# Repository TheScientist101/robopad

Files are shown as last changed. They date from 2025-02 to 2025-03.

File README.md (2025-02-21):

# Robopad

The Robopad was designed because no controllers are mapped correctly for robot simulation. The main features I needed were the two joysticks but I decided to add some sliders to allow me to control the brightness of my screen and some keyswitches to allow me to have more inputs when I need them. Along with the keyswitches, I added some LEDs which will (hopefully) make the macropad look cooler.

## Features

- 2 Joysticks
- 2 Sliders
- 9 Key Switches
- 9 LEDs

## CAD Model

The case was designed using OpenSCAD and fits together using 4 M3 screws which go into threaded inserts. The case is designed to be 3D printed and the files can be found in the `case` and `production` folders.

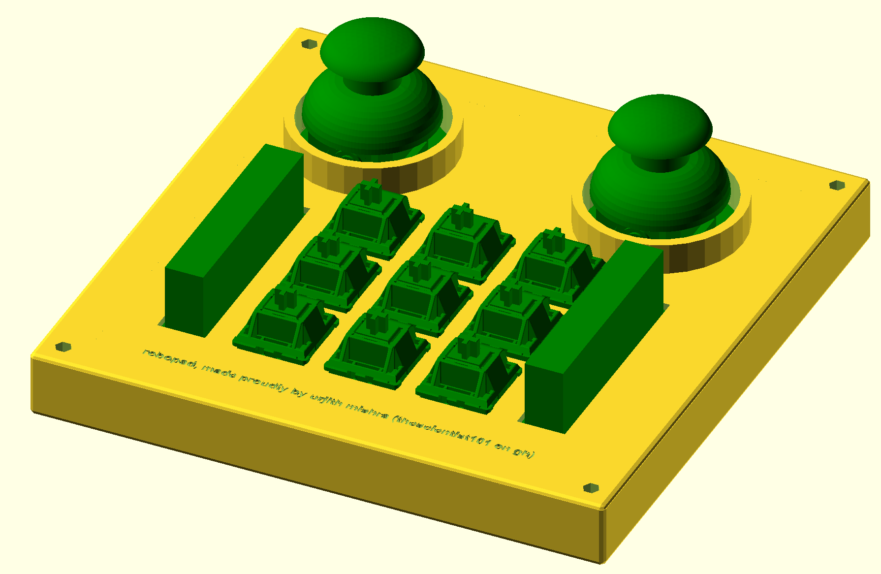
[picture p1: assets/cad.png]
cad


## PCB

My PCB was made in Kicad. It consists of the XIAO Seeed RP2040 microcontroller, 2 joysticks, 2 sliders, 9 keyswitches, and 9 LEDs. The PCB was designed to be 2 layers and the files can be found in the `pcb` folder.

Schematic:\
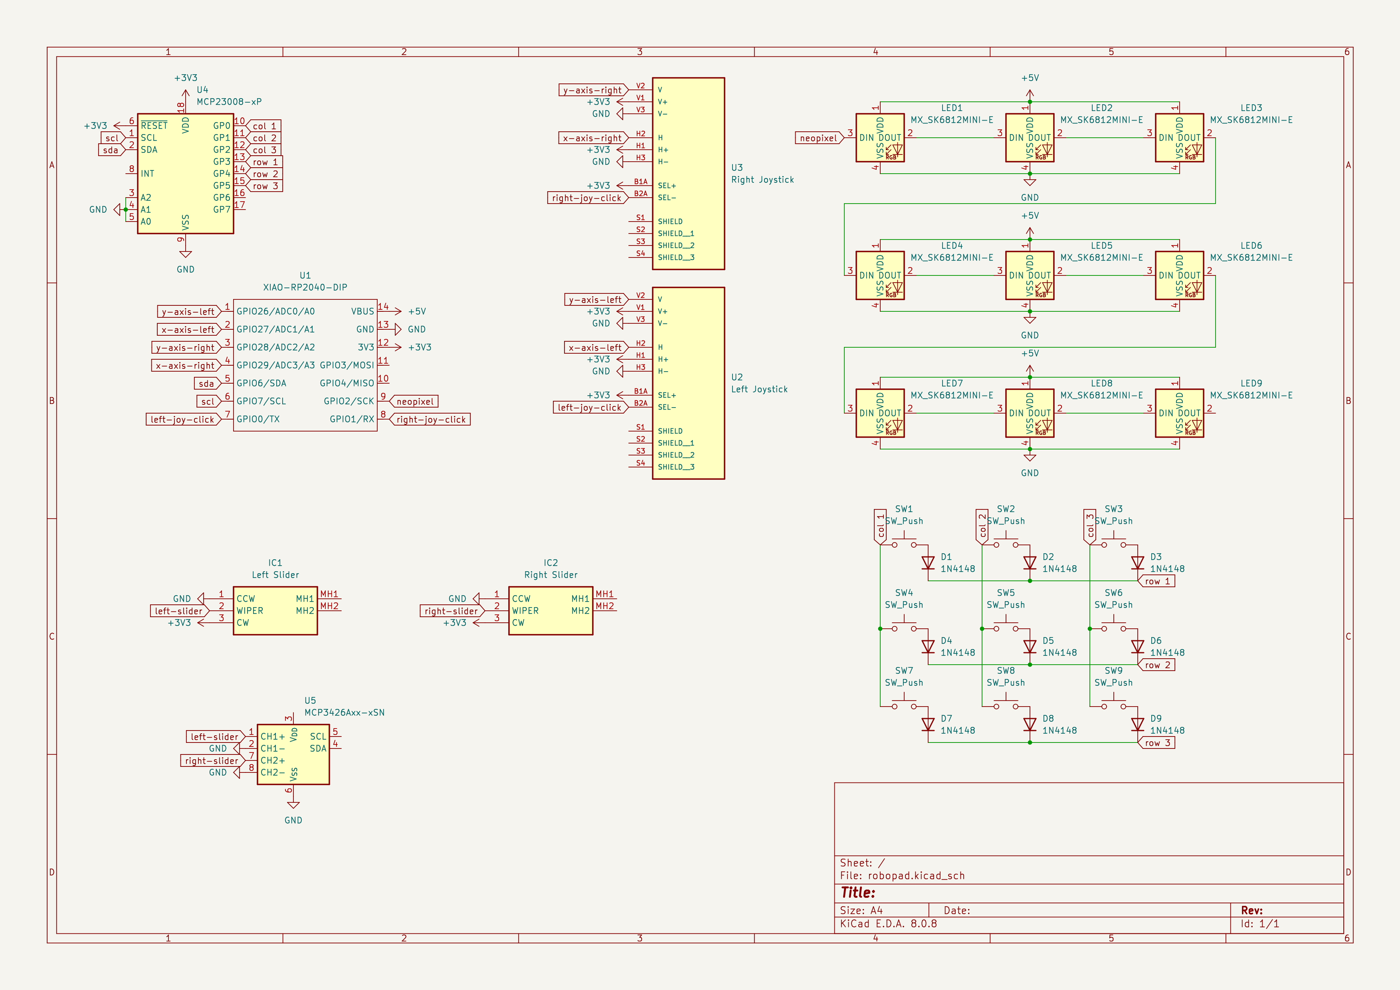
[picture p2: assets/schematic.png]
schematic


PCB:\
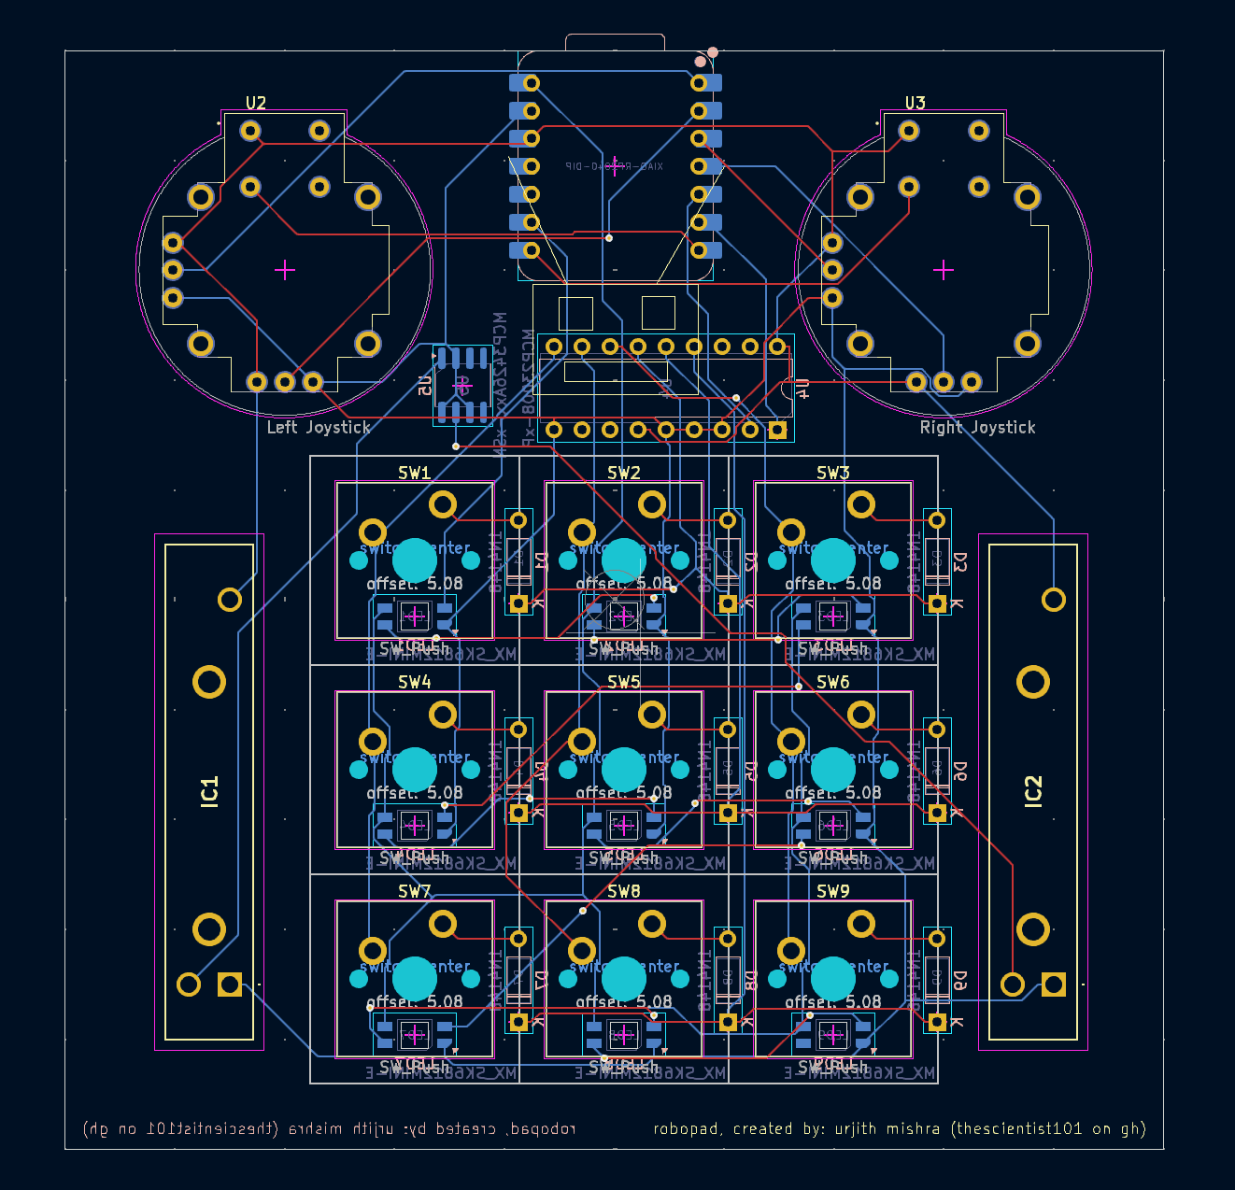
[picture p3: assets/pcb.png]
pcb


## Firmware

The firware was written in Python using KMK and some Adafruit HID stuff. I have a couple different random configurations for the keyswitches. The joysticks should appear as joysticks when plugged in to the computer, and the sliders should change volume and brightness.

## BOM

Stuff from Hackclub:

- 9x Cherry MX Switches
- 9x DSA Keycaps
- 4x M3x5x4 Heatset inserts
- 4X M3x16mm SHCS Bolts
- 9x 1N4148 DO-35 Diodes.
- 9x SK6812MINI-E LEDs
- 1x XIAO RP2040
- 1x Case (2 printed parts)

Stuff from the $20 Grant:

- 1x PCB (black from JLCPCB)
  - $2.00 fabrication + $1.50 shipping + $0.29 tax = $3.79
- 2x Joystick ([from aliexpress](https://www.aliexpress.us/item/3256807502491570.html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))
  - $2.92 (2 in one pack)
- 2x Slider ([from aliexpress](https://www.aliexpress.us/item/2255800687104982.html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))
  - $1.62 \* 2 + $3.66 shipping = $6.90
- 1x MCP3426 I2C ADC ([from aliexpress](https://www.aliexpress.us/item/3256806640672476.html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))
  - $2.38
- 1x MCP23008 I2C GPIO Expander ([from aliexpress](https://www.aliexpress.us/item/2251832814785988.html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))
  - $2.87

Tax from Aliexpress: ($6.90 + $2.38 + $2.87 + $2.92) \* 0.0825 = $1.52
Total: $3.79 + $6.90 + $2.38 + $2.87 + $2.92 + $1.52 + $3.79 = $23.17

If the sales and the stars align I will be able to fit this in the $20 budget. If not, I will pay the extra $3.17.

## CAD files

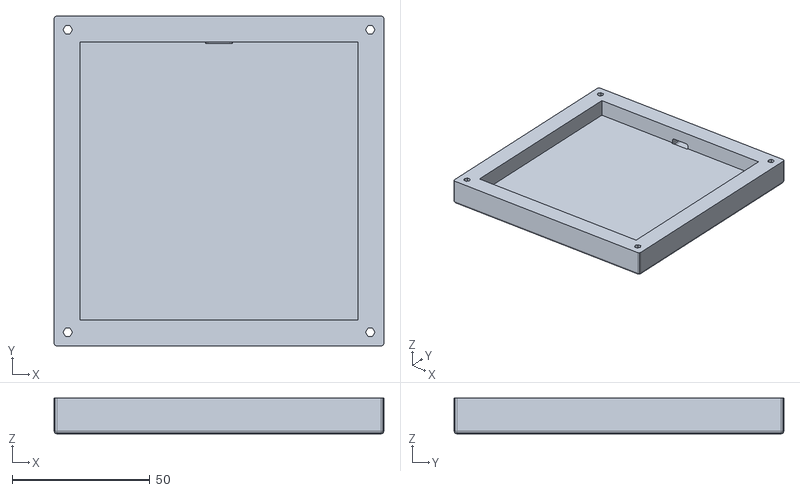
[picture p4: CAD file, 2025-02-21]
production/case_bottom.stl
120.0 x 120.0 x 13.0

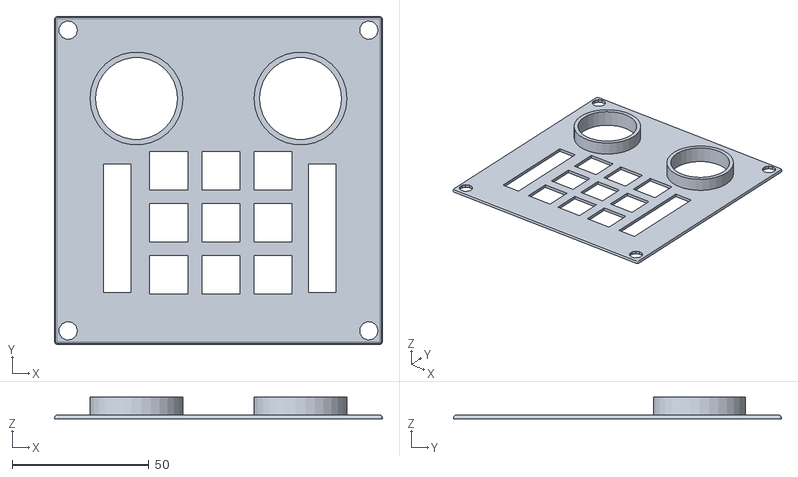
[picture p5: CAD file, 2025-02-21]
production/case_top.stl
120.0 x 120.0 x 8.00

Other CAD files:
cad/assembled.scad
cad/case_bottom.scad
cad/case_top.scad

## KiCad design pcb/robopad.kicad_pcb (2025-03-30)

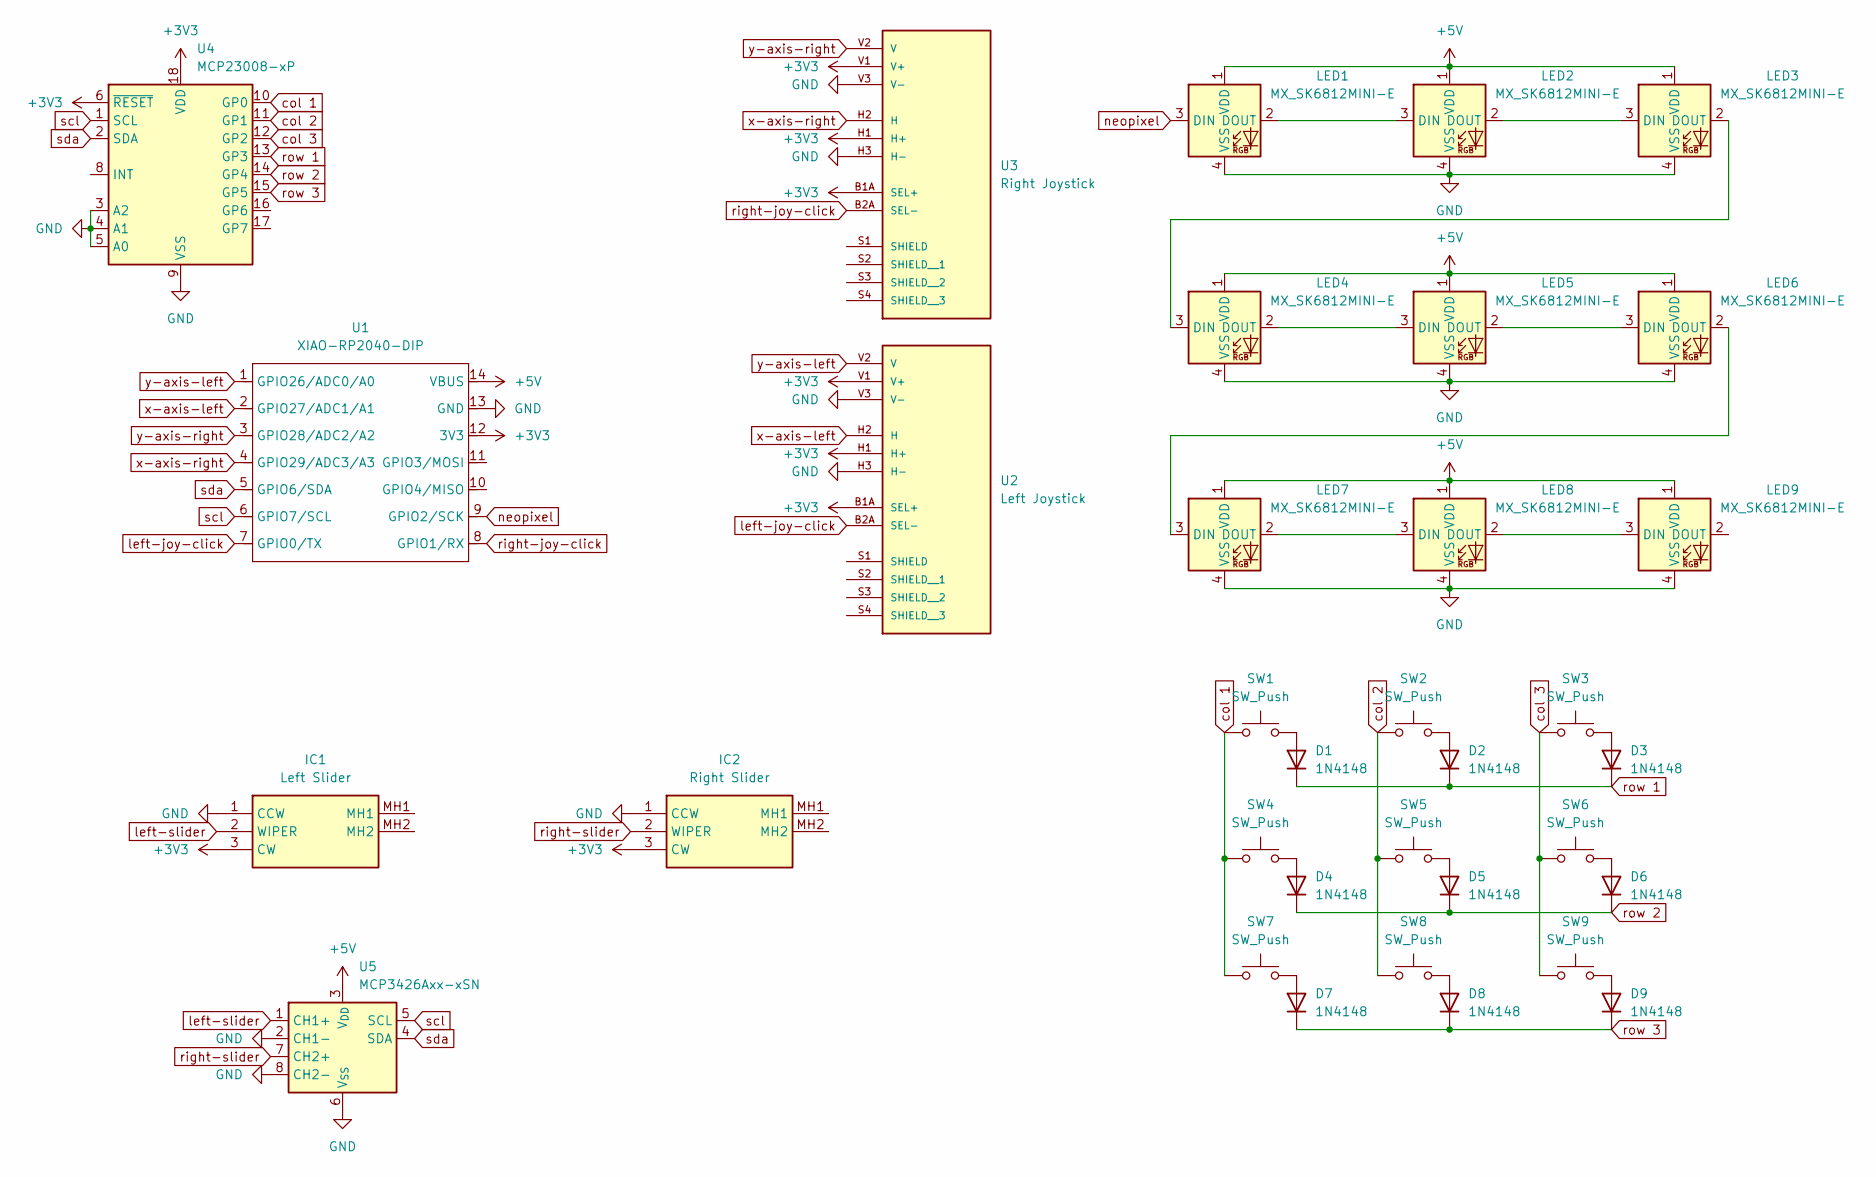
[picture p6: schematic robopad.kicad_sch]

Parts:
D1, D2, D3, D4, D5, D6, D7, D8, D9: 1N4148; D_DO-35_SOD27_P7.62mm_Horizontal
IC1: Left Slider; RS30111AC00V; Mouser Part Number 688-RS30111AC00V
IC2: Right Slider; RS30111AC00V; Mouser Part Number 688-RS30111AC00V
LED1, LED2, LED3, LED4, LED5, LED6, LED7, LED8, LED9: MX_SK6812MINI-E; LED_MX_6028R
SW1, SW2, SW3, SW4, SW5, SW6, SW7, SW8, SW9: SW_Push; SW_Cherry_MX_PCB_1.00u
U1: XIAO-RP2040-DIP; XIAO-SAMD21-DIP
U2: Left Joystick; XDCR_COM-09032; PARTREV N/A
U3: Right Joystick; XDCR_COM-09032; PARTREV N/A
U4: MCP23008-xP; DIP-18_W7.62mm
U5: MCP3426Axx-xSN; SOIC-8_3.9x4.9mm_P1.27mm

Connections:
+3V3: IC1.3 (CW), IC2.3 (CW), U1.12 (3V3), U2.B1A (SEL+), U2.H1 (H+), U2.V1 (V+), U3.B1A (SEL+), U3.H1 (H+), U3.V1 (V+), U4.6 (~RESET), U4.18 (VDD)
+5V: LED1.1 (VDD), LED2.1 (VDD), LED3.1 (VDD), LED4.1 (VDD), LED5.1 (VDD), LED6.1 (VDD), LED7.1 (VDD), LED8.1 (VDD), LED9.1 (VDD), U1.14 (VBUS), U5.3 (V_{DD})
GND: IC1.1 (CCW), IC2.1 (CCW), LED1.4 (VSS), LED2.4 (VSS), LED3.4 (VSS), LED4.4 (VSS), LED5.4 (VSS), LED6.4 (VSS), LED7.4 (VSS), LED8.4 (VSS), LED9.4 (VSS), U1.13 (GND), U2.H3 (H-), U2.V3 (V-), U3.H3 (H-), U3.V3 (V-), U4.3 (A2), U4.4 (A1), U4.5 (A0), U4.9 (VSS), U5.2 (CH1-), U5.6 (V_{SS}), U5.8 (CH2-)
unnamed: D1.2 (A), SW1.2
unnamed: D2.2 (A), SW2.2
unnamed: D3.2 (A), SW3.2
unnamed: D4.2 (A), SW4.2
unnamed: D5.2 (A), SW5.2
unnamed: D6.2 (A), SW6.2
unnamed: D7.2 (A), SW7.2
unnamed: D8.2 (A), SW8.2
unnamed: D9.2 (A), SW9.2
unnamed: LED1.2 (DOUT), LED2.3 (DIN)
unnamed: LED2.2 (DOUT), LED3.3 (DIN)
unnamed: LED3.2 (DOUT), LED4.3 (DIN)
unnamed: LED4.2 (DOUT), LED5.3 (DIN)
unnamed: LED5.2 (DOUT), LED6.3 (DIN)
unnamed: LED6.2 (DOUT), LED7.3 (DIN)
unnamed: LED7.2 (DOUT), LED8.3 (DIN)
unnamed: LED8.2 (DOUT), LED9.3 (DIN)
col 1: SW1.1, SW4.1, SW7.1, U4.10 (GP0)
col 2: SW2.1, SW5.1, SW8.1, U4.11 (GP1)
col 3: SW3.1, SW6.1, SW9.1, U4.12 (GP2)
left-joy-click: U1.7 (GPIO0/TX), U2.B2A (SEL-)
left-slider: IC1.2 (WIPER), U5.1 (CH1+)
neopixel: LED1.3 (DIN), U1.9 (GPIO2/SCK)
right-joy-click: U1.8 (GPIO1/RX), U3.B2A (SEL-)
right-slider: IC2.2 (WIPER), U5.7 (CH2+)
row 1: D1.1 (K), D2.1 (K), D3.1 (K), U4.13 (GP3)
row 2: D4.1 (K), D5.1 (K), D6.1 (K), U4.14 (GP4)
row 3: D7.1 (K), D8.1 (K), D9.1 (K), U4.15 (GP5)
scl: U1.6 (GPIO7/SCL), U4.1 (SCL), U5.5 (SCL)
sda: U1.5 (GPIO6/SDA), U4.2 (SDA), U5.4 (SDA)
x-axis-left: U1.2 (GPIO27/ADC1/A1), U2.H2 (H)
x-axis-right: U1.4 (GPIO29/ADC3/A3), U3.H2 (H)
y-axis-left: U1.1 (GPIO26/ADC0/A0), U2.V2 (V)
y-axis-right: U1.3 (GPIO28/ADC2/A2), U3.V2 (V)

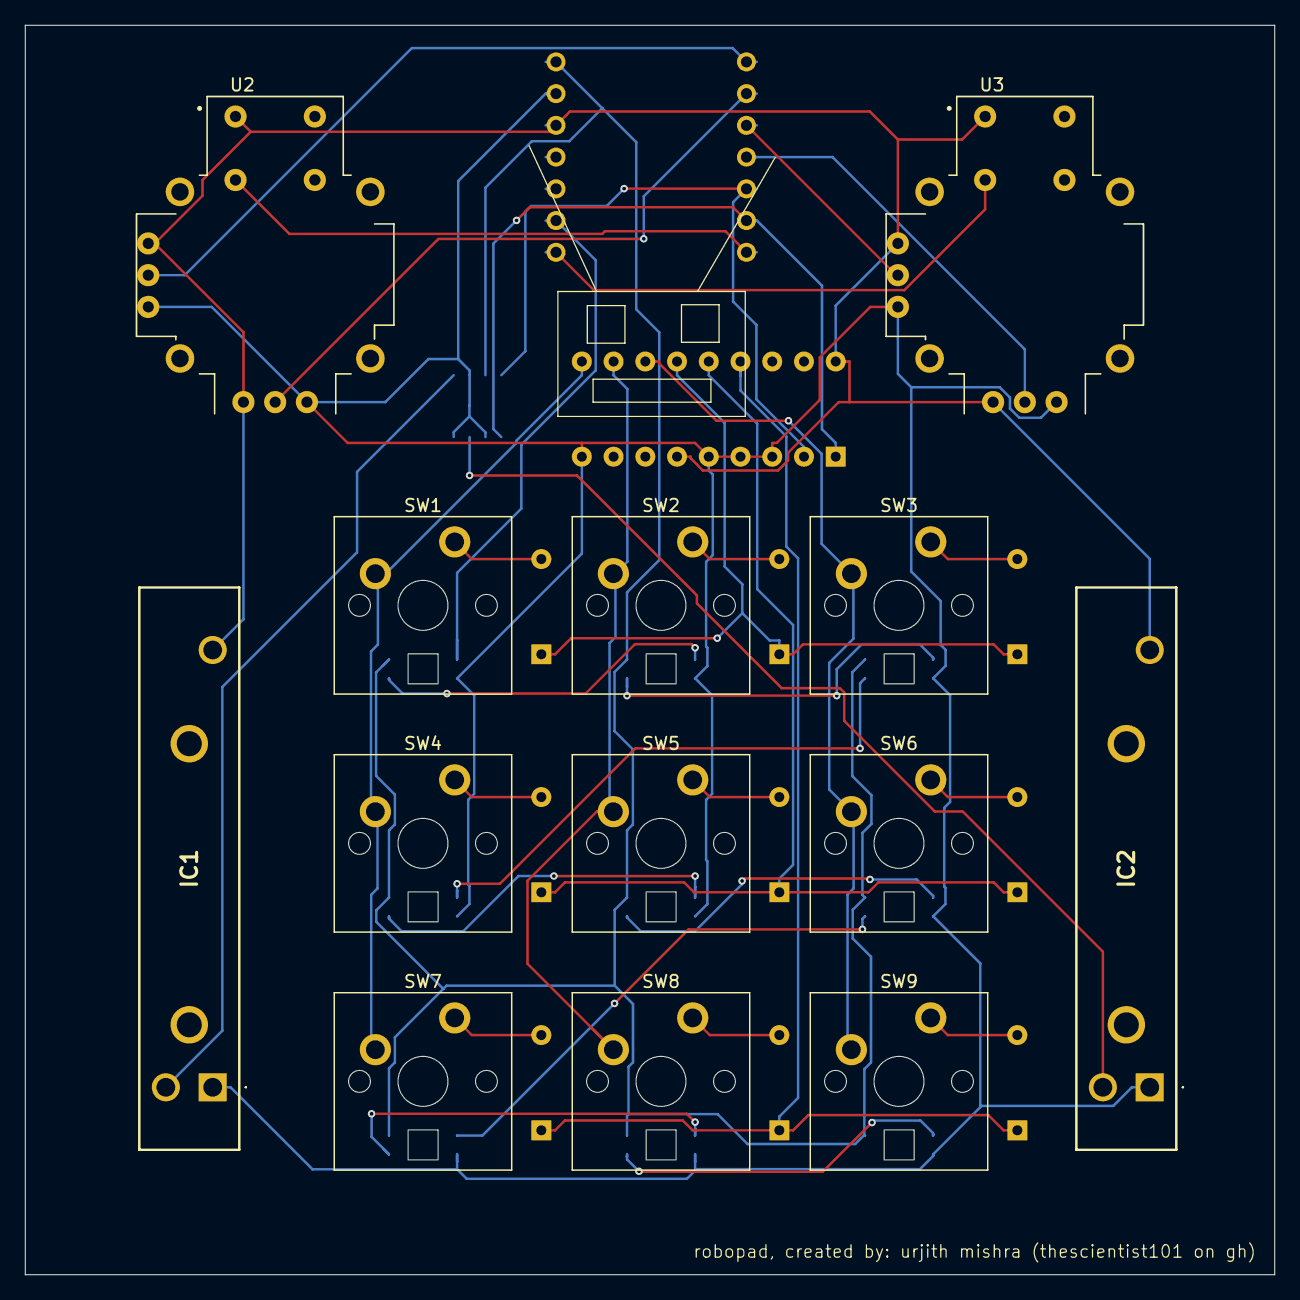
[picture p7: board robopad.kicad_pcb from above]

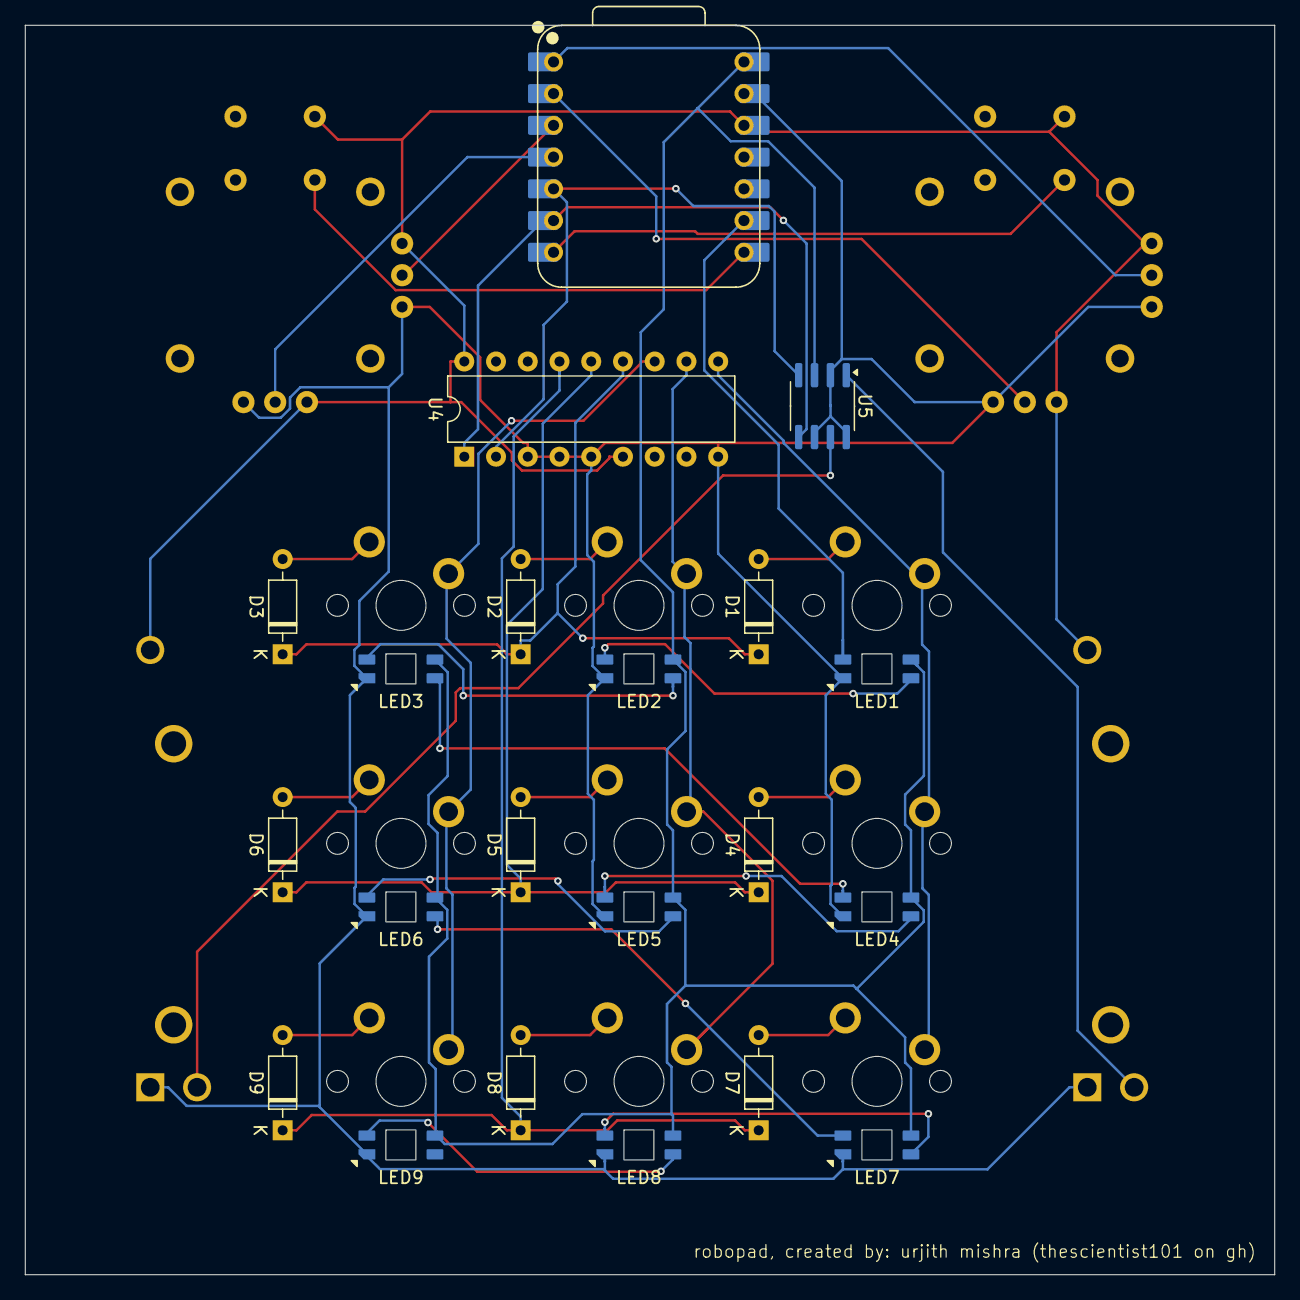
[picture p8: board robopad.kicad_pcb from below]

Board: 2 copper layers, 100.0 x 100.0 mm, 34 parts (21 on the bottom side), 37 nets.

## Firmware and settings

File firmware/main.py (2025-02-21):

import board
import busio
import analogio
import neopixel

from adafruit_mcp3426 import MCP3426
from adafruit_mcp23008 import MCP23008
from kmk.kmk_keyboard import KMKKeyboard
from kmk.keys import KC
from kmk.scanners import DiodeOrientation

import usb_hid
from adafruit_hid.consumer_control import ConsumerControl
from adafruit_hid.consumer_control_code import ConsumerControlCode

import usb_hid

# Source: Adafruit
# TODO: Test with mac to find the correct report descriptor
# This is only one example of a gamepad report descriptor,
# and may not suit your needs.
GAMEPAD_REPORT_DESCRIPTOR = bytes((
    0x05, 0x01,  # Usage Page (Generic Desktop Ctrls)
    0x09, 0x05,  # Usage (Game Pad)
    0xA1, 0x01,  # Collection (Application)
    0x85, 0x04,  #   Report ID (4)
    0x05, 0x09,  #   Usage Page (Button)
    0x19, 0x01,  #   Usage Minimum (Button 1)
    0x29, 0x10,  #   Usage Maximum (Button 16)
    0x15, 0x00,  #   Logical Minimum (0)
    0x25, 0x01,  #   Logical Maximum (1)
    0x75, 0x01,  #   Report Size (1)
    0x95, 0x10,  #   Report Count (16)
    0x81, 0x02,  #   Input (Data,Var,Abs,No Wrap,Linear,Preferred State,No Null Position)
    0x05, 0x01,  #   Usage Page (Generic Desktop Ctrls)
    0x15, 0x81,  #   Logical Minimum (-127)
    0x25, 0x7F,  #   Logical Maximum (127)
    0x09, 0x30,  #   Usage (X)
    0x09, 0x31,  #   Usage (Y)
    0x09, 0x32,  #   Usage (Z)
    0x09, 0x35,  #   Usage (Rz)
    0x75, 0x08,  #   Report Size (8)
    0x95, 0x04,  #   Report Count (4)
    0x81, 0x02,  #   Input (Data,Var,Abs,No Wrap,Linear,Preferred State,No Null Position)
    0xC0,        # End Collection
))

gamepad = usb_hid.Device(
    report_descriptor=GAMEPAD_REPORT_DESCRIPTOR,
    usage_page=0x01,           # Generic Desktop Control
    usage=0x05,                # Gamepad
    report_ids=(4,),           # Descriptor uses report ID 4.
    in_report_lengths=(6,),    # This gamepad sends 6 bytes in its report.
    out_report_lengths=(0,),   # It does not receive any reports.
)

usb_hid.enable(
    (usb_hid.Device.CONSUMER_CONTROL,
     gamepad)
)

cc = ConsumerControl(usb_hid.devices)
gp1 = gamepad(usb_hid.devices)
gp2 = gamepad(usb_hid.devices)

i2c = busio.I2C(board.SCL, board.SDA)

adc = MCP3426(i2c)

mcp = MCP23008(i2c)

joystick_x_left = analogio.AnalogIn(board.GP26)
joystick_y_left = analogio.AnalogIn(board.GP27)
joystick_x_right = analogio.AnalogIn(board.GP28)
joystick_y_right = analogio.AnalogIn(board.GP29)

keyboard = KMKKeyboard()

for pin in range(8):
    mcp.setup(pin, MCP23008.IN)

keyboard.col_pins = [mcp.get_pin(i) for i in range(3)]
keyboard.row_pins = [mcp.get_pin(i + 3) for i in range(3)]

keyboard.keymap = [
    [
        [KC.MUTE, KC.VOLD, KC.VOLU],  # Media controls: Mute, Volume Down, Volume Up
        [KC.PLAY_PAUSE, KC.PREV_TRACK, KC.NEXT_TRACK],  # Media playback controls
        [KC.WEB_SEARCH, KC.NEW_TAB, KC.FIND],  # Web/Browser shortcuts
    ],
    [
        [KC.COPY, KC.PASTE, KC.CUT],  # Editing controls
        [KC.UNDO, KC.REDO, KC.SELECT_ALL],  # Editing shortcuts
        [KC.LCTRL, KC.LALT, KC.LSFT],  # Modifier keys
    ],
    [
        [KC.SCRN, KC.PRTSC, KC.CALC],  # Screenshot and other utilities
        [KC.LGUI, KC.RGUI, KC.SPC],  # GUI keys and space
        [KC.ESC, KC.TAB, KC.ENTER],  # Control keys
    ],
]

keyboard.diode_orientation = DiodeOrientation.COL2ROW

def read_joystick(joystick):
    return int((joystick.value / 65535) * 255) - 127

def update_joystick():
    # Read the joystick values (left and right)
    x_left = read_joystick(joystick_x_left)
    y_left = read_joystick(joystick_y_left)
    x_right = read_joystick(joystick_x_right)
    y_right = read_joystick(joystick_y_right)

    gp1.move_joysticks(
        x=x_left,
        y=y_left,
    )

    gp2.move_joysticks(
        x=x_right,
        y=y_right,
    )

old_volume = 0

def update_volume():
    slider_0_value = adc.read_voltage(channel=0)
    volume_level = int((slider_0_value / 65535) * 100)
    # TODO: make this better
    if volume_level > old_volume:
        cc.send(ConsumerControlCode.VOLUME_INCREMENT)
    elif volume_level < old_volume:
        cc.send(ConsumerControlCode.VOLUME_DECREMENT)
    old_volume = volume_level

old_brightness = 0

def update_brightness():
    slider_1_value = adc.read_voltage(channel=1)
    brightness_level = int((slider_1_value / 65535) * 100)
    if brightness_level > old_brightness:
        cc.send(ConsumerControlCode.BRIGHTNESS_INCREMENT)
    elif brightness_level < old_brightness:
        cc.send(ConsumerControlCode.BRIGHTNESS_DECREMENT)
    old_brightness = brightness_level

pixel = neopixel.NeoPixel(board.GP2, 9, brightness=0.5, auto_write=True)

def fade_colors():
    colors = [
        (255, 0, 0),  # Red
        (0, 255, 0),  # Green
        (0, 0, 255),  # Blue
        (255, 255, 0),  # Yellow
        (0, 255, 255),  # Cyan
        (255, 0, 255),  # Magenta
        (255, 255, 255)  # White
    ]
    while True:
        for color in colors:
            for i in range(256):
                faded_color = tuple(int(c * i / 255) for c in color)
                pixel.fill(faded_color)
                time.sleep(0.01)

def update_inputs():
    update_joystick()
    update_volume()
    update_brightness()

if __name__ == '__main__':
    while True:
        update_inputs()
        keyboard.go()
        fade_colors()

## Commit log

2025-02-21 Add README and add neopixels to firmware
    [assembled.scad, case_bottom.stl, case_top.scad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]
2025-02-21 Add branding
    [case_top.scad, robopad.kicad_pcb]
2025-02-21 Make holes for threaded inserts smaller
    [case_bottom.scad, case_bottom.stl, case_top.scad]
2025-02-21 Re-exported cad and renders to match smaller hole + text
2025-03-30 Plug in sda/scl
    [robopad.kicad_pcb, robopad.kicad_sch]
